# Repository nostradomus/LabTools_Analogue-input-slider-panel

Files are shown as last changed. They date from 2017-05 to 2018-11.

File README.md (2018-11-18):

# **LabTools** : Analogue input slider panel



## What

This slider panel is part of a homemade toolset of modules to simplify the r&d phase of my µ-controller projects. It consists of four [linear slider potentiometers](pdf-files/Bourns-slider-potentiometer-datasheet.pdf), which are connected as [voltage dividers](https://en.wikipedia.org/wiki/Voltage_divider). Built with the component values as stated in the bill-of-materials, the panel is optimized for 0 to 5V ADC's. Thanks to its universal layout, the module can easily be adapted for other voltage ranges, by changing the resistor values.

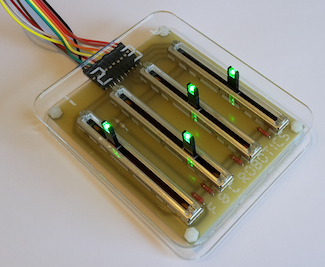
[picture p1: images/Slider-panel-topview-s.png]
Analogue input Slider panel - top view


## Why

Whilst playing around with µ-controllers and their peripherals, I got often confronted with the need for analogue values for various reasons.
 - When designing a [ternary clock](https://github.com/nostradomus/Base3-clock) I had a need to mix my own cool colors to display with the RGB LED's in this project. The slider panel was just what I needed, as I could easily simulate the three color channels red, green and blue, plus the brightness on the fourth slider.
 - Next on a rainy Sunday, we decided to have some fun, and build our version of the [cool O++O robot](https://github.com/OttoDIY/OttoDIY). This cute little guy is running, or rather, dancing on four servos. In a project with *constrainted* movements, it is interesting to test the mechanical limits of your rotations before breaking any of your nice 3D-printed parts. YAGA ! **Yet another great application** for the slider panel.
 - When working with servos, not only the angular limits are important, but for several applications also the center point of the circular movement. This came in handy for a robot arm project based on radial coordinates.  
 - A completely different, but obvious example, was application testing. For practical reasons, most of the time, it is preferable to replace physical sensors by **controlled** test values. In pure programming these usually originate from test units. With this type of methodology however, it is utmost impossible to do exhaustive testing. Especially when combining multiple analogue values. For that matter, as an extra test, the slider panel has proven to be very handy.  
 - And their will probably be dozens of other useful applications for this little lab tool...

## How

Simple projects don't need complicated specifications. However once you start, there's always a couple of nice-to-haves you just have to go for.
 - The [slider potentiometers](pdf-files/Bourns-slider-potentiometer-datasheet.pdf) should  
    - have a reasonable travel length for precision
    - have a linear taper
    - have a center detent
    - exist in different resistance values (10kΩ and higher)
    - have a built-in indicator LED
 - The [housing](#mechanical-construction) should have
    - an ID for each slider
    - labels for each pin on the interface connector
 - And the whole thing must be **fancy** :sunglasses: !

## Progress status

 - [x] having a [need](#why)
 - [x] define the [functional specifications](#how)
 - [x] design the final [electronics](#electronics)
 - [x] build a proof-of-concept for the final [electronics](#electronics)
 - [x] write [code for the µ-controller](#µ-controller-code) respecting best-practices
 - [x] design and build a [state-of-the-art housing](#mechanical-construction)
 - [x] validate the [application examples](#µ-controller-code) with in-line documentation

## Technical details

### The voltage divider, the ADC and the mapping function

The whole setup of this mini-project is based on three crucial denominators, two in the electronics, and one in software.

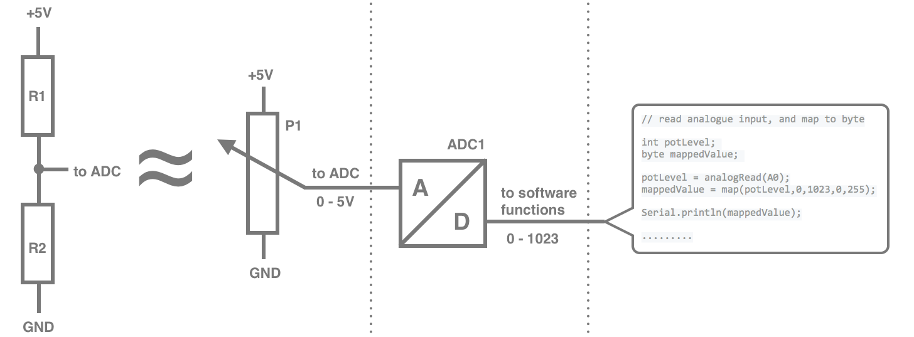
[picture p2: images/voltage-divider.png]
Voltage divider - ADC - mapping function


The first part of the magic happens inside the potentiometer which is connected as a [voltage divider](https://en.wikipedia.org/wiki/Voltage_divider). Some current will flow from +5V to ground through the 10kΩ resistor. The third wire (or center tap) of the potentiometer gives us a variable connection on that 10kΩ range, which actually splits it into two resistors (which add up to be the full resistance). In such a passive resistive-only circuit, the center tap will output a voltage which is proportional to the total potential, the same way as the fractions of the two resistors are to the total resistance. Next, as the [chosen slider potentiometer](pdf-files/Bourns-slider-potentiometer-datasheet.pdf) is of good linear quality, the output will even be equally proportional to the slider's position on the total slider travel length.  

The second step is where the µ-controller will convert this (physical) voltage in a software readable value. This is called an [ADC, or analogue-to-digital converter](https://en.wikipedia.org/wiki/Analog-to-digital_converter). They exist in numerous varieties of architectures, conversion types, speeds, precision... For the below examples, I will use the [ATmega328p](pdf-files/datasheet-ATmega328P.pdf)'s built-in ADC's. They are marked as A0, A1, A2... Being of 10-bit precision, the conversion of the 0 to 5V voltage will give a value between 0 and 1023. More details on this specific ADC can be found from [page 237 to 248 in the µ-controller's datasheet](pdf-files/datasheet-ATmega328P.pdf).

The last trick to be done is converting the 0 to 1023 value to the range for our application. In below examples, colors and PWM outputs need to be set. All of these need byte-values. For PWM 0 to 255, and for RGB-colors (0..255,0..255,0..255). You could of course write some simple equations to apply the rule of three. However the C-language in the [Arduino IDE](https://www.arduino.cc/en/Main/Software) is having a very handy function for that, called [mapping](https://www.arduino.cc/en/reference/map).
```C
recalculated_value = map(value, fromLow, fromHigh, toLow, toHigh);
// example : x = map(511,0,1023,0,255)
//           -> gives x = 127
```
### The Electronics

#### The Schematic

The electronics setup is straightforward and easy to understand. Four [variable resistors P1 to P4 (linear sliders), or potentiometers](pdf-files/Bourns-slider-potentiometer-datasheet.pdf) are connected between +5V and ground. Depending on the position, the slider-pin will output a voltage between 0 and 5V. This can be directly connected to your µ-controller's analogue input, or ADC. The (optional) LED's in the slider button have been fit with 2,7kΩ resistors (R1 to R4), to limit the current flowing through, and to not make you blind :sunglasses:. For connector CON1, a **90° bent** 10x1 pin-header is preferred, for easy access in combination with the laser-cut housing.

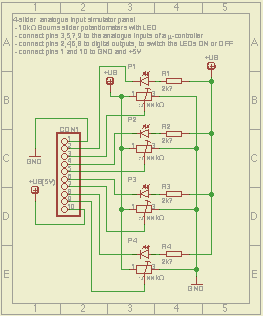
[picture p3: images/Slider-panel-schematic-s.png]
Schematic design


#### The PCB

The PCB has been designed single-sided with wide traces for "kitchen-brew" production. The larger pcb size and generous spacing between the [potentiometers](pdf-files/Bourns-slider-potentiometer-datasheet.pdf) is mainly for ergonomical reasons. Be precise when drilling the holes in the pcb, as the quality of the mechanical construction depends on correct positioning of the potentiometers and the four mounting holes.

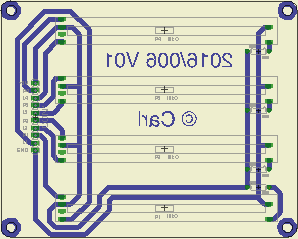
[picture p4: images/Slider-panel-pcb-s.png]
PCB design


#### BOM - bill of materials

Part | Value | Package | Description  
---- | ----- | ------- | -----------                                                                      
R1,2,3,4 | 2,7kΩ | 0204/7             | resistor                                            
P1,2,3,4 | 10kΩ  | SLIDER_POT_60_WLED | Bourns slider potentiometer (60mm) with LED
CON1     | 1x10  | 1x10 90°           | 90° bent pin header

#### Connection with a µ-controller board

The board has been designed with a 10-way (90° bent) pin-header for easy connection with standard Dupont lines, typically used for testing during breadboard phase.

:electric_plug:|name |description
---------------|-----|----------------------------------
1              |GND  | ground
2              |LED1 | indicator led on potentiometer 1
3              |P1   | variable output on potentiometer 1
4              |LED2 | indicator led on potentiometer 2
5              |P2   | variable output on potentiometer 2
6              |LED3 | indicator led on potentiometer 3
7              |P3   | variable output on potentiometer 3
8              |LED4 | indicator led on potentiometer 4
9              |P4   | variable output on potentiometer 4
10             |+5V  | 5 volt power Connection

In a minimum setup, pins 1 and 10 (power and ground), and at least one Px output need to be connected. When using an Arduino eco-system, the potentiometer's variable output can be connected directly to any of the µ-controller's analogue inputs which accept 0 to 5V. The *optional* led connections can either be connected directly to the ground (always ON), or to a digital output of the µ-controller (capable of sinking at least 10mA). When building the full project (lasercut plexi included), you will see the connection descriptors engraved in the rear-panel, just above the pin-header.

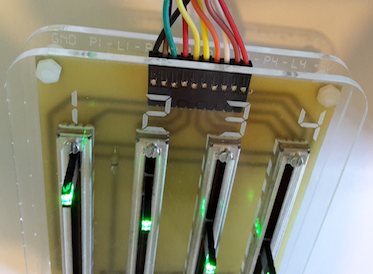
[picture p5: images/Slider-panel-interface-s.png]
Analogue input Slider panel - interface view


### µ-Controller code

The demo/test software has been written in the free [Arduino IDE](https://www.arduino.cc/en/Main/Software), or as [sourcecode](https://github.com/arduino/Arduino/).
These examples are using the [servo library](https://www.arduino.cc/en/Reference/Servo), which is included in the Arduino IDE software, and [Adafruit's Neopixel library](https://github.com/adafruit/Adafruit_NeoPixel). All sketches can be found in the [source-folder](source/).

#### Application example 1 : Robot servo calibration

A basic [servo calibration application](source/robotarm-servo-calibration.ino) is available in the [source-folder](source/). The Arduino sketch contains extensive comments on how to connect and run the application. The basic idea is to first find the clockwise :leftwards_arrow_with_hook: and counterclockwise :arrow_right_hook: limits of a servo inside your mechanical construction. Secondly, in many construction you might also be interested in the mid-point between these to limits. And, this is not necessarily CW :leftwards_arrow_with_hook: plus CCW :arrow_right_hook: divided by two ! Next, in the serial monitor, you can read the settings to be used in your future application. By using the CW :leftwards_arrow_with_hook: and CCW :arrow_right_hook: limits as parameters 4 and 5 in the mapping function, you can easily prevent mechanical overshoot (and damage) while fine-tuning your mechanics. Before connecting your mechanical construction, it would be a good idea to set the slider potentiometers at 50%, and to position your servos about half-way of their possible movement. When starting the application, the serial monitor will provide connection and setup info. Next, the software will slowly move the servos to the position as preset by the potentiometers. Once the sketch reaches the main-loop, things might be more reactive. So, handle with care :collision: :exclamation: When changing the value of a slider, its button LED will remain ON, as long as the servo is moving towards its new angular position.

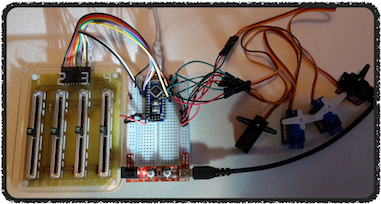
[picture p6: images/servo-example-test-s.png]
Servo calibrater - test setup


#### Application example 2 : RGB LED color mixer

A basic [color mixer application](source/RGB-LED-color-mixer.ino) is available in the [source-folder](source/). The Arduino sketch contains extensive comments on how to connect and run the application. The basic idea is to brew your own color by mixing R(ed), G(reen) and B(lue) until you like the result visually. Next, in the serial monitor, you can read the settings to be used in your future application (0..255,0..255,0..255). Slider number 4 will let you play with the overall brightness, and provide feedback in the serial monitor accordingly. When starting the application, the serial monitor will provide connection and setup info, followed by a short LED test.

For those who prefer more fancy feedback, an extended version of the [color mixer application](source/RGB-LED-color-mixer-with-indicators.ino) is also available. This version has code implemented to use the LED's on the slider buttons. When one of the sliders is moved, its button-LED will switch ON. This indicates that the associated value had a change above the preset threshold (configurable value). The LED will remain ON for three seconds (configurable value).

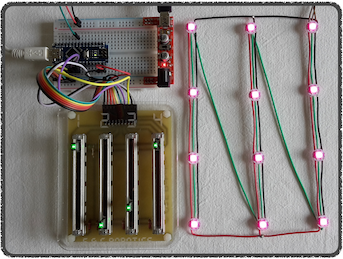
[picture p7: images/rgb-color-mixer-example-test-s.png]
RGB color mixer - test setup


### Mechanical construction

The housing consists of two layers of lasercut and engraved plexi plates. I would suggest to use 3mm of thickness. When using another thickness, pay attention to adapt the length of screws and bolts.

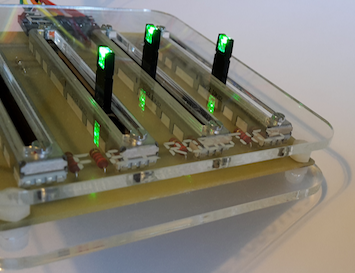
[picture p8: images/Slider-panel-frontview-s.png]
Analogue input Slider panel - front view


Material :
 - 4 nylon bolts, M3 x 8
 - 8 nylon nuts, M3
 - 8 metal screws, M2 x 4 (optionally with conic head)

The four nylon bolts fit in the four holes of the rear plexi plate. The heads should be down, as they will serve as feet for the module. The rear panel has to be turned, in a way that the connector info (GND-P1-L1-P2...) is readable on the top. Next four nylon bolts are fit on the threading (which points up). These standard bolts are thick enough to serve as spacers for the PCB, which has to be fit on top. The other four nylon bolts will be used to fix the PCB. The front plate (with 1-2-3-4 on top) is fixed on the metal slider housings with the 8 metal screws. The prototype has been built with standard flat-head screws. The 3mm plexi is however thick enough to be adapted for screws with a conic head (extra milling required).

## Contributors

If you are having any good suggestions, just drop me a line [:email:](http://nostradomus.ddns.net/contactform.html).
If feasible, I'll be happy to implement proposed improvements.
And if you are having lots of time, I'll be happy to share the work with you ;-).

When you create your own version, don't forget to send us some nice pictures of your construction. We'll be happy to publish them in the :confetti_ball:Hall of Fame:confetti_ball:.

## :globe_with_meridians: License

There is no specific license attached to this project for personal use.

If you like it, have fun with it (at your own risk of course :-D), and especially, be creative.

Oh, and when using anything from this repository, it is highly appreciated if you mention its origin.

If you would like to use any of my work (or the whole project) for commercial use, just [contact me :email:](http://nostradomus.ddns.net/contactform.html), so we can agree on an appropriate license, which best fits your business.

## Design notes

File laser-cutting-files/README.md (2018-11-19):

This folder contains all files required to laser-cut and engrave the plexi plates for the housing.

For the initial built, 3 mm plexi material has been used.  

When using another thickness, the length of the srews and bolts should be adapted.

The .cdr-files have been created with CorelDraw, and have been optimized for [Trotec laser and engraving machines](https://www.troteclaser.com/en/). The .svg-files contain the same drawings (created with [free InkScape](https://inkscape.org)), and might be better for processing in [open-hardware laser-cutting machines](https://onlfait.ch/fablab/services/machines/).

Three different RGB-colors have been used :

 - black : engraving
 - red : internal cut-outs
 - blue : outline cut

The compressed file [```digital-font.zip```](digital-font.zip) contains the .ttf font-files which have been used for the engraving. They might not be installed on your system. It concerns a free (for personal use) font which was downloaded from the internet somewhere in the 20th century, for which unfortunately the referring website does not exist anymore (http://digitalfont.hypermart.net).

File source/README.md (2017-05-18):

This folder contains all source code related to this project :

 - robotarm-servo-calibration.ino : Arduino sketch to show how the slider panel can be used to calibrate servo movement
 - RGB-LED-color-mixer.ino : Arduino sketch to show how the slider panel can be used to mix colors for RGB LED's

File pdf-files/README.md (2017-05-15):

This folder contains : 
 - PDF exports to produce and build the PCB for the shield without using the EAGLE software
 - PDF exports of the laser-cutting files
 - PDF versions of various documents (which require specific software)
 - Datasheets concerning the used components

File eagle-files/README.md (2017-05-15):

This folder will contain all files required to open the project in the EAGLE PCB software [(download here)](http://www.autodesk.com/products/eagle/free-download) : 

 - .epf : the project file as main entry point (is connected with the description file)
 - .sch : schematic file
 - .brd : pcb layout file
 
 These files should (grouped in a folder) either be copied in Eagle's project directory (see below image of the settings window). The Eagle directory settings also accept multiple paths. The Eagle syntax requires columns as path separators.

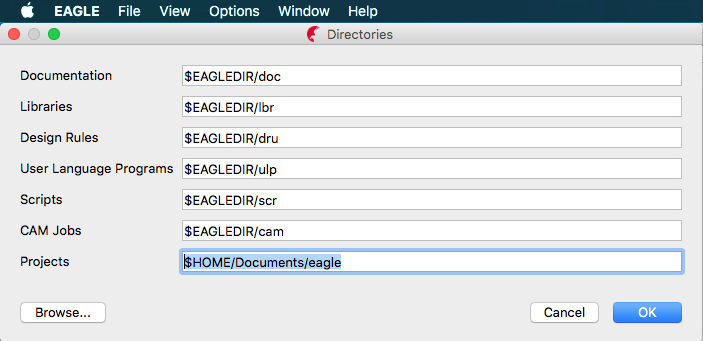
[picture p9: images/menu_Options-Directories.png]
Directory settings


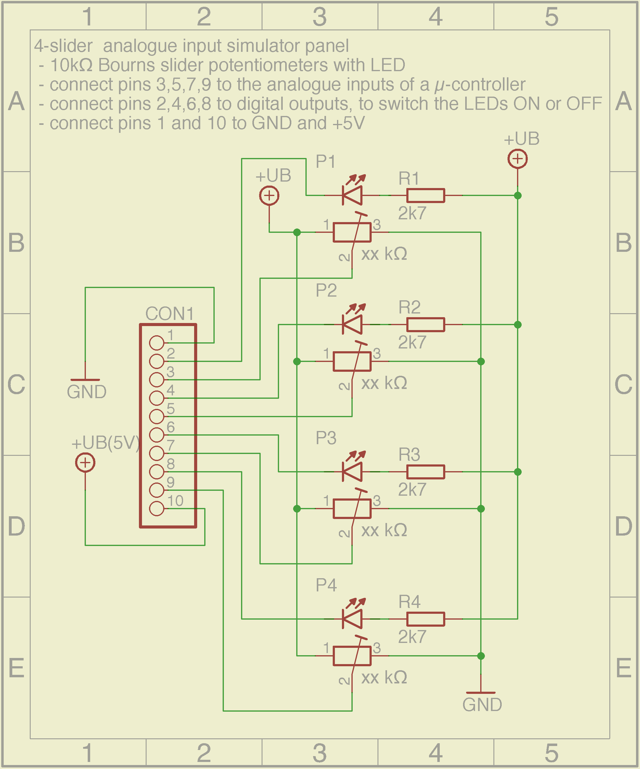
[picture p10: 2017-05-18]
images/Slider-panel-schematic.png

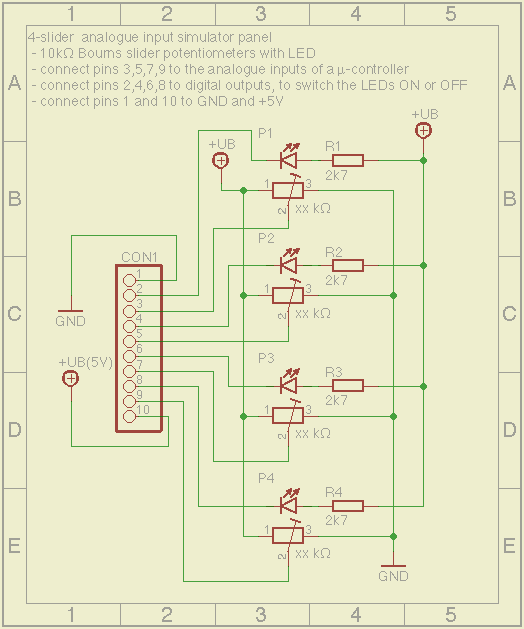
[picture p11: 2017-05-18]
images/Slider-panel-schematic-m.png

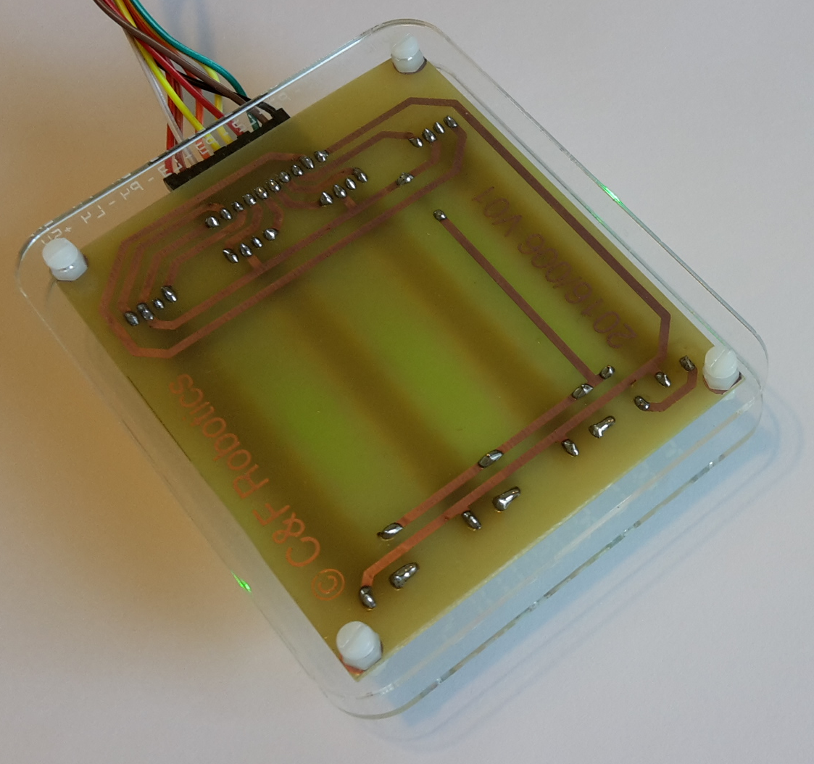
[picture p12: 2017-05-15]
images/Slider-panel-pcbview.png

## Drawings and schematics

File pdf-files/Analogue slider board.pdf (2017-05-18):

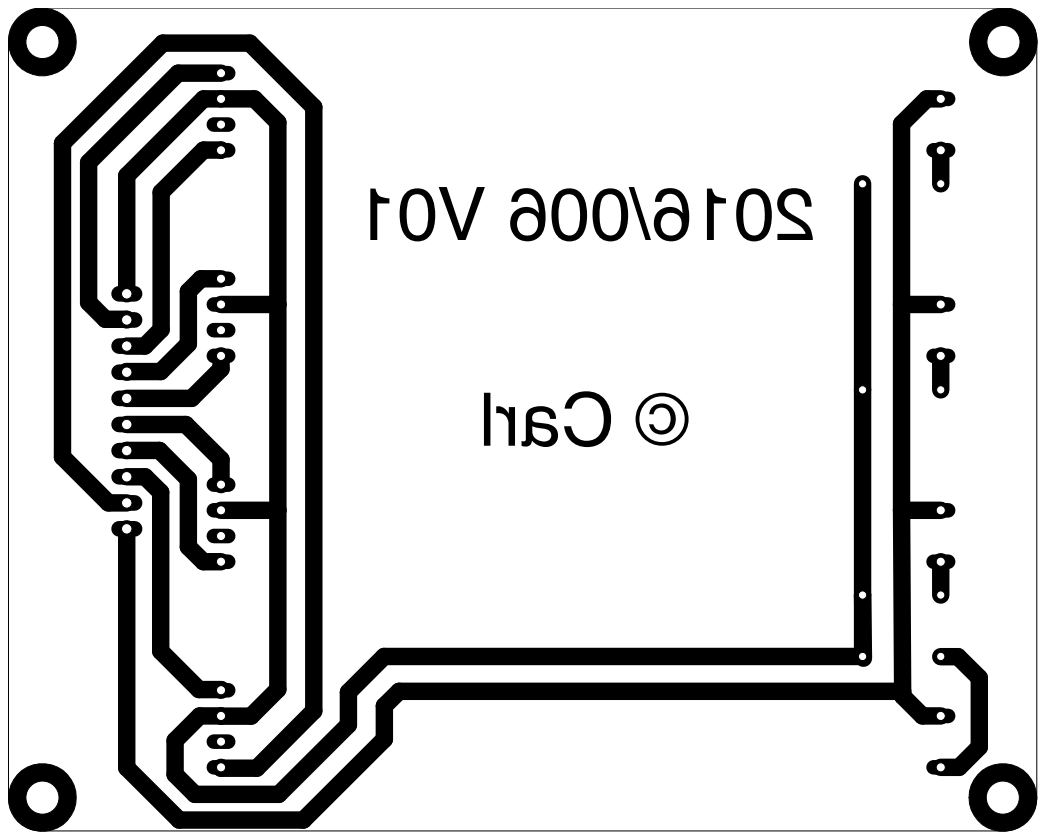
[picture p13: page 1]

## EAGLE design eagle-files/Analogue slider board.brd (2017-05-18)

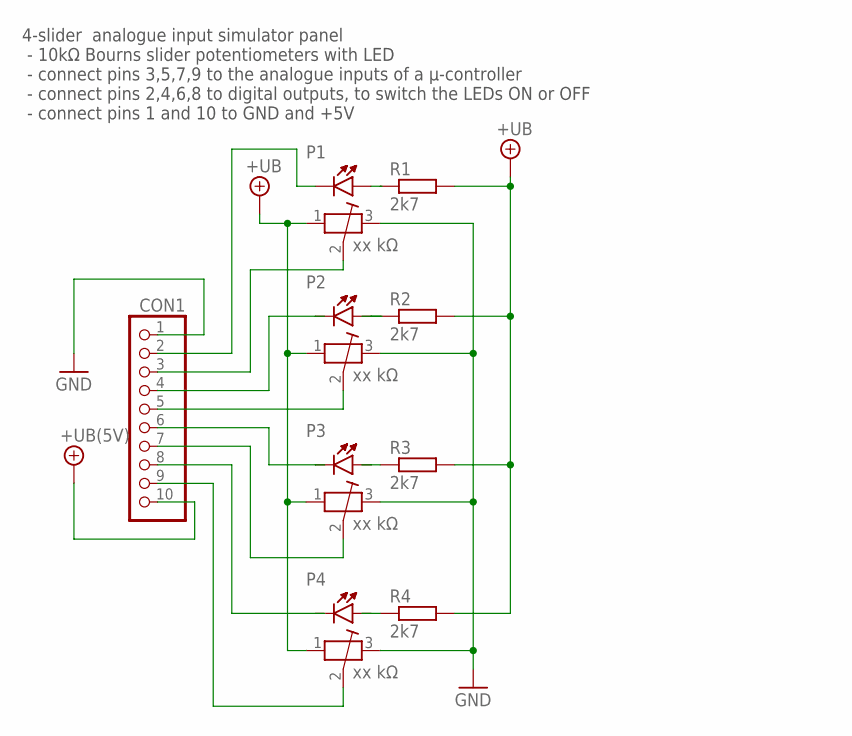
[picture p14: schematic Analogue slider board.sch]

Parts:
CON1: PINHD-1X10; 1X10
P1, P2, P3, P4: 10kΩ; SLIDER_POT_60_WLED
R1, R2, R3, R4: 2k7; 0204/7

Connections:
+UB: CON1.10, P1.1, P2.1, P3.1, P4.1, R1.2, R2.2, R3.2, R4.2
GND: CON1.1, P1.3, P2.3, P3.3, P4.3
unnamed: P1.B (B(+)), R1.1
unnamed: P2.B (B(+)), R2.1
unnamed: P3.B (B(+)), R3.1
unnamed: P4.B (B(+)), R4.1
unnamed: CON1.3, P1.2
unnamed: CON1.5, P2.2
unnamed: CON1.7, P3.2
unnamed: CON1.9, P4.2
unnamed: CON1.8, P4.E (E(-))
unnamed: CON1.6, P3.E (E(-))
unnamed: CON1.4, P2.E (E(-))
unnamed: CON1.2, P1.E (E(-))

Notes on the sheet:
4-slider analogue input simulator panel - 10kΩ Bourns slider potentiometers with LED - connect pins 3,5,7,9 to the analogue inputs of a µ-controller - connect pins 2,4,6,8 to digital outputs, to switch the LEDs ON or OFF - connect pins 1 and 10 to GND and +5V

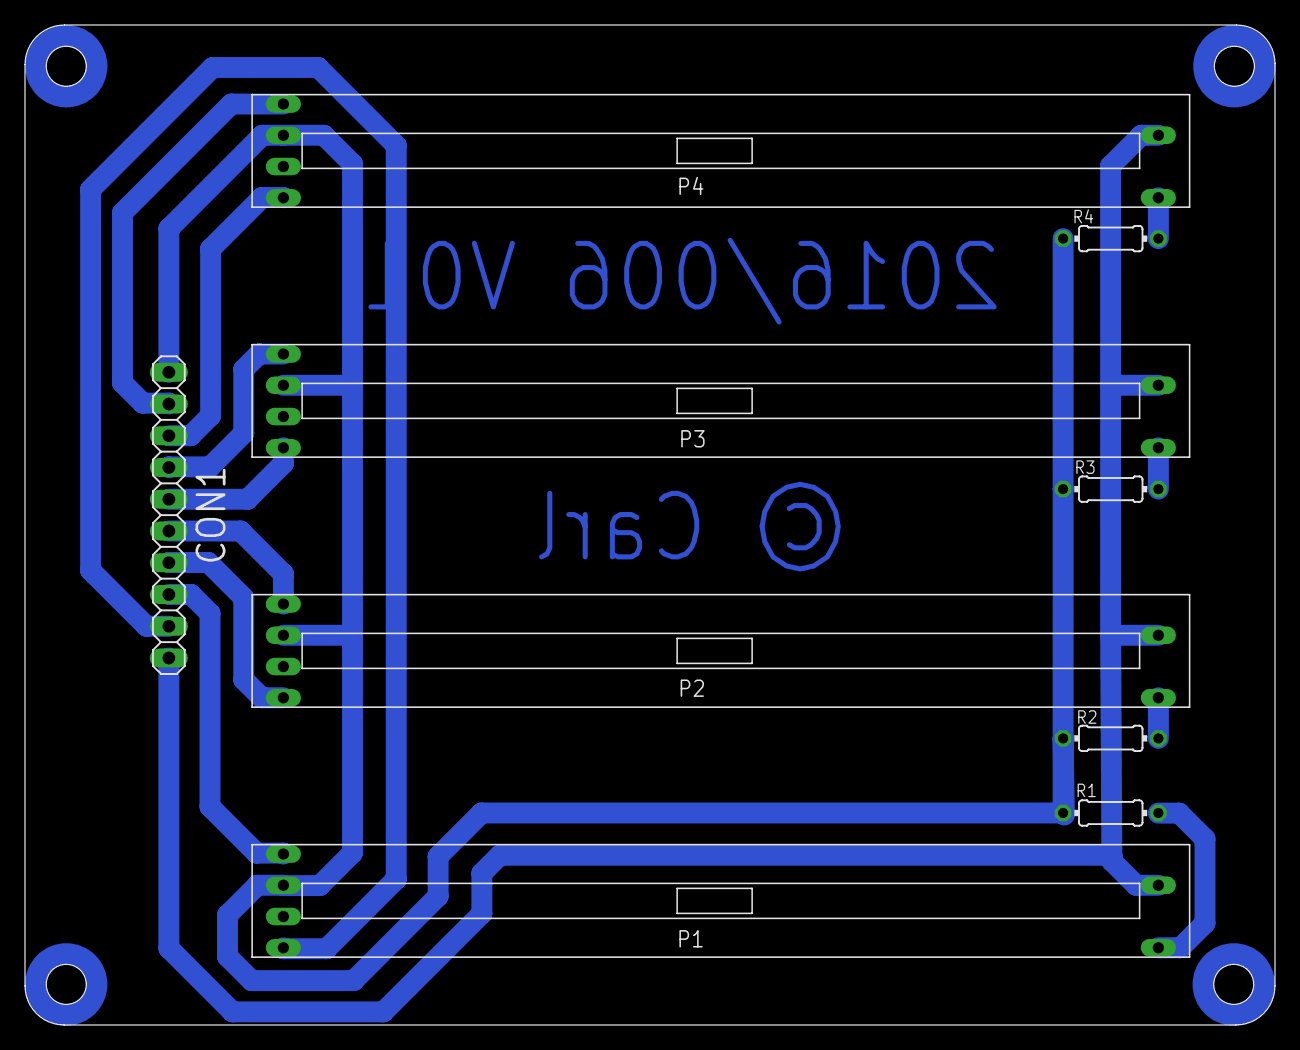
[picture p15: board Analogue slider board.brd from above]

Board: 2 copper layers, 100.0 x 80.0 mm, 9 parts (0 on the bottom side), 14 nets.

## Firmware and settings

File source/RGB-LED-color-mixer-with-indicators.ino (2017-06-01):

//***************************************************
//**            RGB LED color mixer                **
//**            with indicators                    **
//**                                               **
//**   author : Carl - (c)2017                     **
//**   version : 1.0                               **
//**   date : 01/06/2017                           **
//**                                               **
//**   https://github.com/nostradomus/             **
//**          LabTools_Analogue-input-slider-panel **
//**                                               **
//***************************************************
// In this example the 12 WS2812b RGB-LED's have been connected in series
// For testing purposes, the RGB LED interface board from project : 
// https://github.com/nostradomus/Base3-clock has been used
// Any number of these LED's can be used with this example
// Just adapt the first parameter in the "strip"'s constructor call (and foresee a strong enough power-supply ;-)
// You might need to modify the third parameter as well, when using other LED-types 

// This version of the application also uses the LED's on the slider
// buttons to indicate which channel was used for the most recent changes.
// The respective LED (or LED's) will stay ON, for the time as configured in LEDupTime.

//***************************************************
//**             library section                   **
//***************************************************
#include <Adafruit_NeoPixel.h>     // library required to control the WS2812B LED's, 
                                   // see : https://github.com/adafruit/Adafruit_NeoPixel
//***************************************************
//**            constants section                  **
//***************************************************
#define dataPIN 6                               // output pin for the neopixel dataline. On Arduino NANO, in this example we used 'D6'
                                                // to be adapted to your setup
#define channelCount 4                          // number of connected channels
#define LEDupTime 4000                          // time the LED will stay ON after the last change
#define serialUpdateFilter 4                    // filter with minimum change before sending new values to the serial monitor
#define buttonUpdateFilter 2                    // filter with minimum change to update the button LED's

const int sliderLEDpins[] = {12,8,7,4};         // an array of general purpose I/O pins to attach the LED's
                                                // on the sliders. The LED's will switch ON to indicate which color channel has been updated
static const uint8_t ADCpins[] = {A0,A1,A2,A3}; // the 4 ADC inputs to be used for the slider potentiometers   

//***************************************************
//**         global variables section              **
//***************************************************

int bLevel = 127;                             // brightness level 0..255 (initial value at 50%)
int checksum = 0;                             // RGB checksum, to only print to serial in case of changes

byte newChannelValue[] = {0,0,0,0};           // new RGB and brightness values from the analogue inputs
byte previousChannelValue[] = {0,0,0,0};      // previous RGB and brightness values stored from the previous measuremnts 
long LEDstartTime[] = {0,0,0,0};              // Variables to check the time-out to switch the button LED's to OFF

Adafruit_NeoPixel strip = Adafruit_NeoPixel(12, dataPIN, NEO_GRB + NEO_KHZ800);
// Parameter 1 = number of pixels connected on the dataline
// Parameter 2 = Arduino pin number 
// Parameter 3 = LED-pixel type settings, add add-up in case of combinations:
//   NEO_KHZ800  800 KHz bitstream -> most common (WS2812 LEDs)
//   NEO_KHZ400  400 KHz -> classic types ('v1' (not v2) FLORA pixels, WS2811 drivers)
//   NEO_GRB     Pixels with GRB bitstream (most NeoPixel products), or NEO_GRBW
//   NEO_RGB     Pixels with RGB bitstream (v1 FLORA pixels, not v2), or NEO_RGBW
// (for more info, please check out the documentation on Adafruit's github : 
//  https://github.com/adafruit/Adafruit_NeoPixel)

//presets for fixed LED colors
uint32_t dark = strip.Color(0, 0, 0);         // LED pixel -> OFF            
uint32_t green = strip.Color(0, 255, 0);      // LED pixel -> green
uint32_t red = strip.Color(255, 0, 0);        // LED pixel -> red
uint32_t blue = strip.Color(0, 0, 255);       // LED pixel -> blue
uint32_t white = strip.Color(255, 255, 255);  // LED pixel -> white

//***************************************************
//**               setup section                   **
//***************************************************
void setup() {
  Serial.begin(115200);                            // initialize the serial communication 
  Serial.println(".");
  Serial.println(" ");
  Serial.println("*********************************************************");
  Serial.println("**             RGB LED color mixer - (c)2017           **");
  Serial.println("**  - Serial communication initialized                 **");
  strip.begin();

  strip.setBrightness(bLevel);                    // set the LED-pixel brightness 
  strip.show();                                   // Initialize all pixels to 'OFF'
  Serial.print("** - LED brightness set to : ");
  Serial.println(bLevel);
  Serial.println("** - LED strip initialized                             **");
  // configure the LED pins as outputs
  for (int LEDpin = 0; LEDpin < channelCount; LEDpin++) {
    pinMode(sliderLEDpins[LEDpin], OUTPUT);
    digitalWrite(sliderLEDpins[LEDpin], HIGH);
    }
  // perform a short 'lamp test'
  // all LED's will be switched ON, one at a time (and switched OFF afterwards)
  for (int LEDpin = 0; LEDpin < channelCount; LEDpin++) {
    digitalWrite(sliderLEDpins[LEDpin], LOW);
    delay(500);
    }
  for (int LEDpin = channelCount - 1; LEDpin >= 0; LEDpin--) {
    digitalWrite(sliderLEDpins[LEDpin], HIGH);
    delay(500);
    }
  Serial.println("** - slider LED's initialized                          **");  
  Serial.println("**                   Setup completed...                **");
  Serial.println("*********************************************************");
  Serial.println("**  make sure that the slider panel is correctly       **");
  Serial.println("**  connected to your Arduino :                        **");
  Serial.println("**  pin 1  : GND to ground                             **");
  Serial.println("**  pin 2  : L1 to D12 -> LED on slider 1              **");
  Serial.println("**  pin 3  : P1 to A0 -> RED                           **");
  Serial.println("**  pin 4  : L1 to D8 -> LED on slider 1               **");
  Serial.println("**  pin 5  : P2 to A1 -> GREEN                         **");
  Serial.println("**  pin 6  : L1 to D7 -> LED on slider 1               **");
  Serial.println("**  pin 7  : P3 to A2 -> BLUE                          **");
  Serial.println("**  pin 8  : L1 to D4 -> LED on slider 1               **");
  Serial.println("**  pin 9  : P4 to A3 -> brightness                    **");
  Serial.println("**  pin 10 : +5V to the power supply                   **");
  Serial.println("*********************************************************");
  Serial.println(" ");
  Serial.println("Your LED's will now change color a couple of times to make sure that all is well connected...");
  strip.setBrightness(63);
  for(uint16_t i=0; i<strip.numPixels(); i++) {strip.setPixelColor(i, red);}
  strip.show();
  Serial.println("RED..............");
  delay(1000);
  strip.setBrightness(127);
  for(uint16_t i=0; i<strip.numPixels(); i++) {strip.setPixelColor(i, green);}
  strip.show();
  Serial.println("...GREEN.........");
  delay(1000);
  strip.setBrightness(195);
  for(uint16_t i=0; i<strip.numPixels(); i++) {strip.setPixelColor(i, blue);}
  strip.show();
  Serial.println("........BLUE.....");
  delay(1000);
  strip.setBrightness(255);
  for(uint16_t i=0; i<strip.numPixels(); i++) {strip.setPixelColor(i, white);}
  strip.show();
  Serial.println("............WHITE");
  delay(1000);
  Serial.println("...and from here on you can start playing with the sliders...");
  Serial.println(" ");  
  }

//***************************************************
//**            main application loop              **
//***************************************************
void loop() {
  //run the color calibration procedure
  runColorCalibrationProcedure(); 
  }

//***************************************************
//** application specific functions and procedures **
//***************************************************

// calibrate the colors with the slider potentiometers on analogue inputs A0 to A3
// the analogue slider and serial monitor need to be connected to use this function
// read-out the shown color on the serial monitor 
void runColorCalibrationProcedure() {            
      // read the current values on the analogue inputs and process them
      for (int i = 0; i < channelCount; i++) {
          newChannelValue[i] = map(analogRead(ADCpins[i]), 0, 1023, 0, 255);
          if (abs(newChannelValue[i] - previousChannelValue[i]) > buttonUpdateFilter) {
            previousChannelValue[i] = newChannelValue[i];
            LEDstartTime[i] = millis();
            digitalWrite(sliderLEDpins[i], LOW);
            } else {
              if ((millis() - LEDstartTime[i]) > LEDupTime) {
                digitalWrite(sliderLEDpins[i], HIGH);}
              }
          }
      bLevel = newChannelValue[3];
      int newChecksum = newChannelValue[0] + newChannelValue[1] + newChannelValue[2] + bLevel;
      if (abs(checksum - newChecksum) > serialUpdateFilter) {
          // update the LED's if any value has been changed on the analogue inputs
          // you can change the <serialUpdateFilter> value in the equation to obtain more or less updates
          // 0 will give you all changes (might cause an enormous amount of serial communication)
          // 3 will mask potentiometer jitter, but still provide close enough values for the mixed color
          // The <serialUpdateFilter> constant can set in the 'constants section'
          checksum = newChecksum;
          // send the new values to the serial monitor
          Serial.print("Color : R-");
          Serial.print(newChannelValue[0]);
          Serial.print(" -G ");
          Serial.print(newChannelValue[1]);
          Serial.print(" -B ");
          Serial.print(newChannelValue[2]);
          Serial.print(" -brightness ");
          Serial.println(bLevel);
          // set the LED-pixel brightness
          strip.setBrightness(bLevel);
          // prepare the data-frame with color-info for each LED-pixel
          uint32_t c = strip.Color(newChannelValue[0], newChannelValue[1], newChannelValue[2]);
          for(uint16_t i=0; i<strip.numPixels(); i++) 
           {
           strip.setPixelColor(i, c);
           }
          // submit the new settings to all LED-pixels
          strip.show();  
      }
}

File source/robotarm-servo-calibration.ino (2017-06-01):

//***************************************************
//**          ROBOT servo calibration              **
//**                                               **
//**   author : Carl - (c)2017                     **
//**   version : 1.0                               **
//**   date : 01/05/2017                           **
//**                                               **
//**   https://github.com/nostradomus/             **
//**          LabTools_Analogue-input-slider-panel **
//**                                               **
//***************************************************

//***************************************************
//**             library section                   **
//***************************************************

#include <Servo.h>                              // library required to control servos by PWM 
      
//***************************************************
//**            constants section                  **
//***************************************************
// This demo application has been written with Arduino Nano as target eco-system
// The sketch can easily be adapted for other systems, by simply adapting the pin numbers
// Any system running on 5V can be used with below sourcecode
// For each servo under test, a PWM output, an analogue input and a general I/O pin are required   

#define servoUpdateDelay 50                     // 15ms delay, after any servo action (default for library = 15ms)
#define DUTcount 4                              // number of Devices Under Test

const int servoPWMpins[] = {5,6,9,10};          // an array of PWM capable output pins to attach servos 1 to 4
                                                // each servo has 3 connections : ground, 5V power and a PWM signal
const int servoLEDpins[] = {12,8,7,4};          // an array of general purpose I/O pins to attach the LED's
                                                // on the sliders. The LED's will switch ON to indicate which servo is moving
static const uint8_t ADCpins[] = {A0,A1,A2,A3}; // the 4 ADC inputs which will be used for the slider potentiometers                                        
                        
//***************************************************
//**         global variables section              **
//***************************************************

Servo servos[4];                                // create 4 servo objects

boolean printUpdateToSerial = true;             // flag to indicate whether updated values should be sent to the serial monitor

//***************************************************
//**               setup section                   **
//***************************************************
void setup() {
  Serial.begin(115200);                         // initialize the serial communication 
  Serial.println(".");
  Serial.println("*********************************************************");
  Serial.println("**        ROBOT servo calibration tool - (c)2017       **");
  Serial.println("**  - Serial communication initialized                 **");
  // configure the LED pins as outputs
  for (int LEDpin = 0; LEDpin < DUTcount; LEDpin++) {
    pinMode(servoLEDpins[LEDpin], OUTPUT);
    digitalWrite(servoLEDpins[LEDpin], HIGH);
    }
  // perform a short 'lamp test'
  // all LED's will be switched ON, one at a time (and switched OFF afterwards)
  for (int LEDpin = 0; LEDpin < DUTcount; LEDpin++) {
    digitalWrite(servoLEDpins[LEDpin], LOW);
    delay(500);
    }
  for (int LEDpin = DUTcount - 1; LEDpin >= 0; LEDpin--) {
    digitalWrite(servoLEDpins[LEDpin], HIGH);
    delay(500);
    }
  Serial.println("** - LED's initialized                                 **");
  Serial.println("**                   Setup completed...                **");
  Serial.println("*********************************************************");
  Serial.println("**  make sure that the slider panel is correctly       **");
  Serial.println("**  connected to your Arduino Nano :                   **");
  Serial.println("**  pin 1  : GND to ground                             **");
  Serial.println("**  pin 2  : L1 to D12 -> LED on slider 1              **");
  Serial.println("**  pin 3  : P1 to A0 -> servo 1                       **");
  Serial.println("**  pin 4  : L2 to D8 -> LED on slider 2               **");
  Serial.println("**  pin 5  : P2 to A1 -> servo 2                       **");
  Serial.println("**  pin 6  : L3 to D7 -> LED on slider 3               **");
  Serial.println("**  pin 7  : P3 to A2 -> servo 3                       **");
  Serial.println("**  pin 8  : L4 to D4 -> LED on slider 4               **");
  Serial.println("**  pin 9  : P4 to A3 -> servo 4                       **");
  Serial.println("**  pin 10 : +5V to the power supply                   **");
  Serial.println("*********************************************************");
  Serial.println("**  connect all servos correctly to the Arduino Nano : **");
  Serial.println("**  all GND's to ground, all +5V to the power supply   **");
                 //  -> an external power supply might be needed, as
                 //     the Nano board can only provide limited current
  Serial.println("**  PWM input servo 1 -> D5                            **");
  Serial.println("**  PWM input servo 2 -> D6                            **");
  Serial.println("**  PWM input servo 3 -> D9                            **");
  Serial.println("**  PWM input servo 4 -> D10                           **");
  Serial.println("*********************************************************");
  Serial.println(" ");
  Serial.println("Your servos will now move to their initial position.");
  Serial.println("Please wait until all LED's are OFF...");
  for (int DUTid = 0; DUTid < DUTcount; DUTid++){moveServo(servos[DUTid],DUTid,90);}  
  Serial.println("...and from here on you can start playing with the sliders...");
  Serial.println(" "); 
  }

//***************************************************
//**            main application loop              **
//***************************************************
void loop() {
  //run the servo calibration procedure
  runServoCalibration(); 
  }

//***************************************************
//** application specific functions and procedures **
//***************************************************
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

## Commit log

2017-06-01 Potentiometer jitter masking mechanism updated
    [RGB-LED-color-mixer.ino]
2017-06-01 Alternative version for color calibration with button LED indicators uploaded

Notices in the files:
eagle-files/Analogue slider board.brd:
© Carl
